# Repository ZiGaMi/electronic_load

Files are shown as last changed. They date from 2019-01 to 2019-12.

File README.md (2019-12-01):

# Electronic Load Rev1.1 
# 
Supports constant current (CC), constant power (CP) and constant resistance modes (CR).

Power rating: 12 W        
Maximum load current: 1 A           
Maximum input voltage: 12 V
 
 Electronic load front:
front

Electronic load backside:
back

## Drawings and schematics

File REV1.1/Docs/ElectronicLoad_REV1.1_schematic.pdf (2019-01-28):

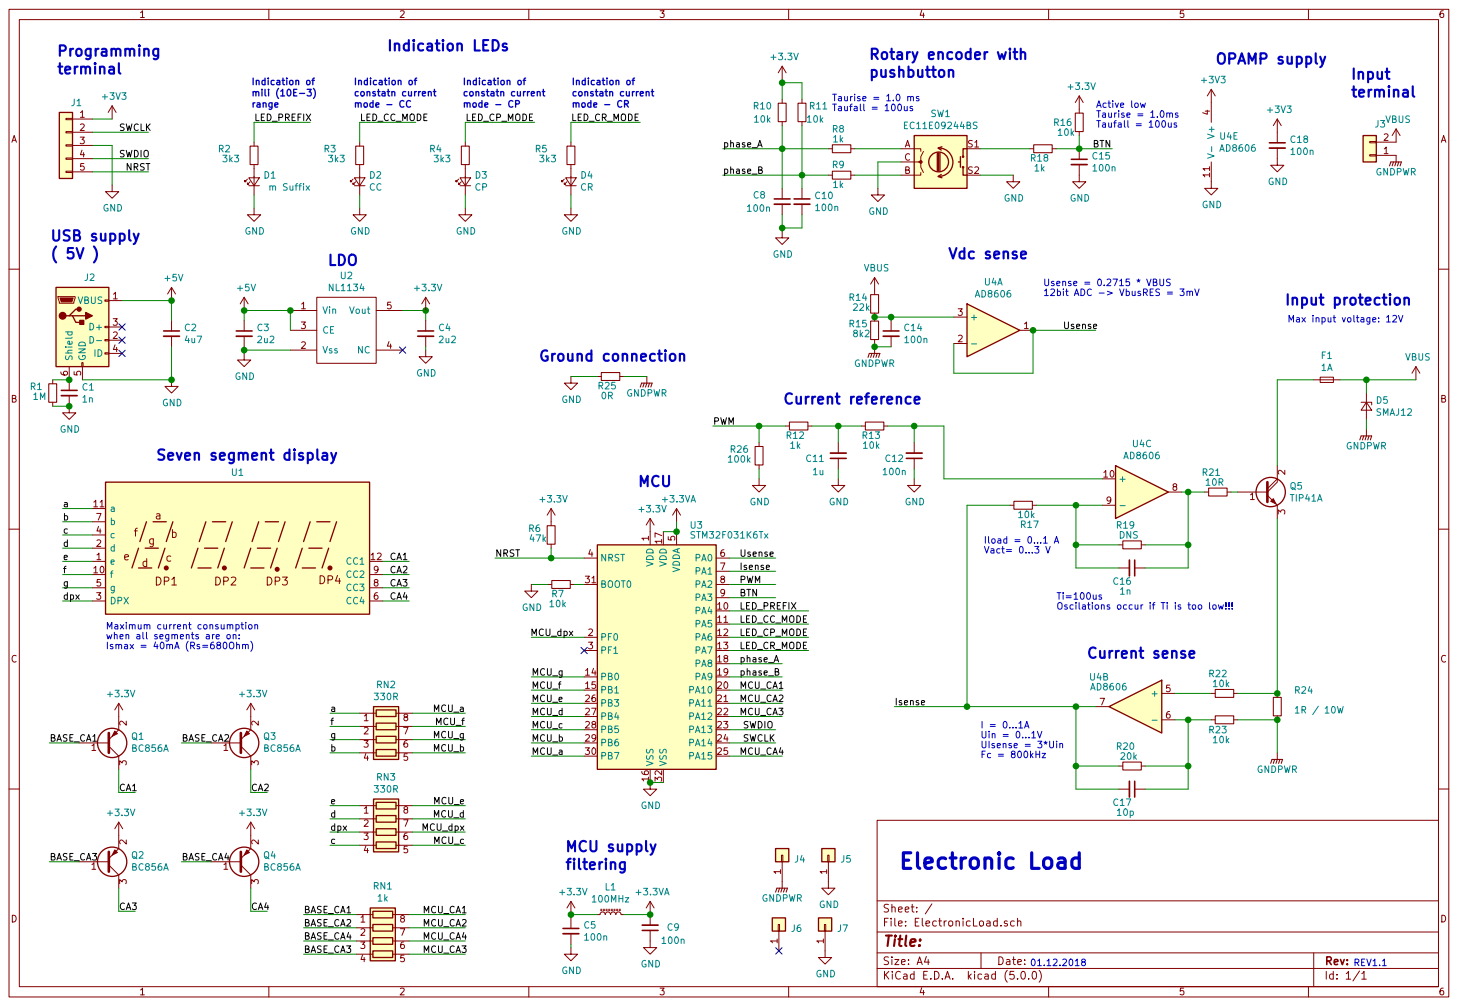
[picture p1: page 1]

Taurise = 1.0ms Taufall = 100us Taurise = 1.0 ms Taufall = 100us Rotary encoder with
pushbutton

Indication of mili (10E-3) range

Indication of constatn current mode - CC

Indication of constatn current mode - CP

Indication of constatn current mode - CR

2 3 Q1BC856A CA1 +3.3V Maximum current consumption
when all segments are on:
Ismax = 40mA (Rs=680Ohm)1

I = 0...1A Uin = 0...1V UIsense = 3*Uin Fc = 800kHz

Id: 1/1 Title: File: ElectronicLoad.sch Sheet: /

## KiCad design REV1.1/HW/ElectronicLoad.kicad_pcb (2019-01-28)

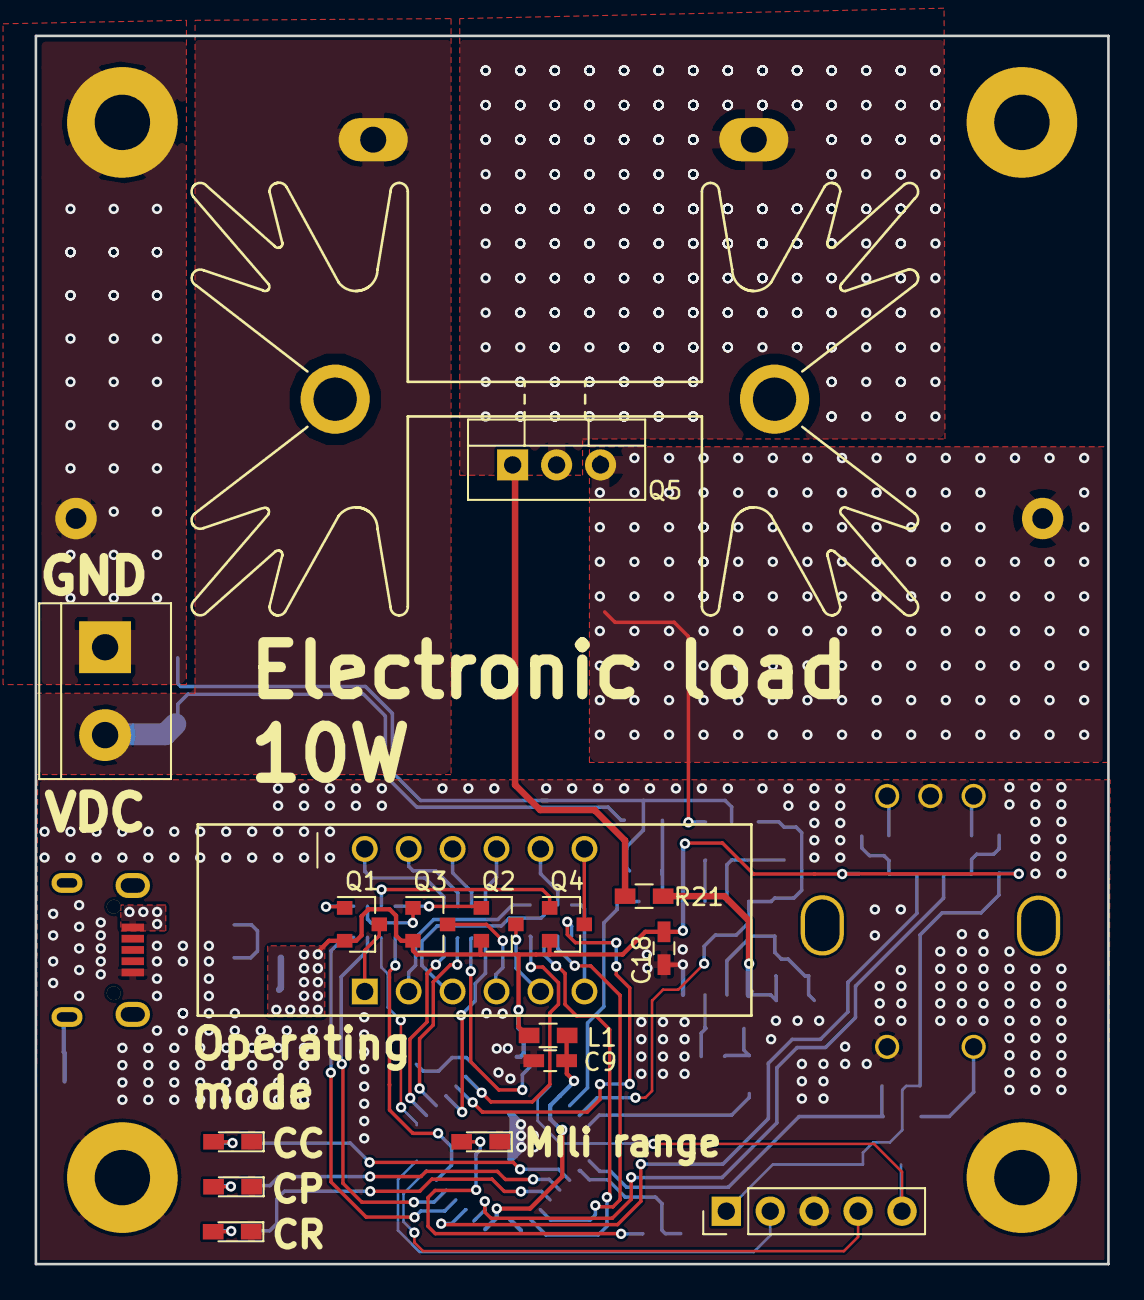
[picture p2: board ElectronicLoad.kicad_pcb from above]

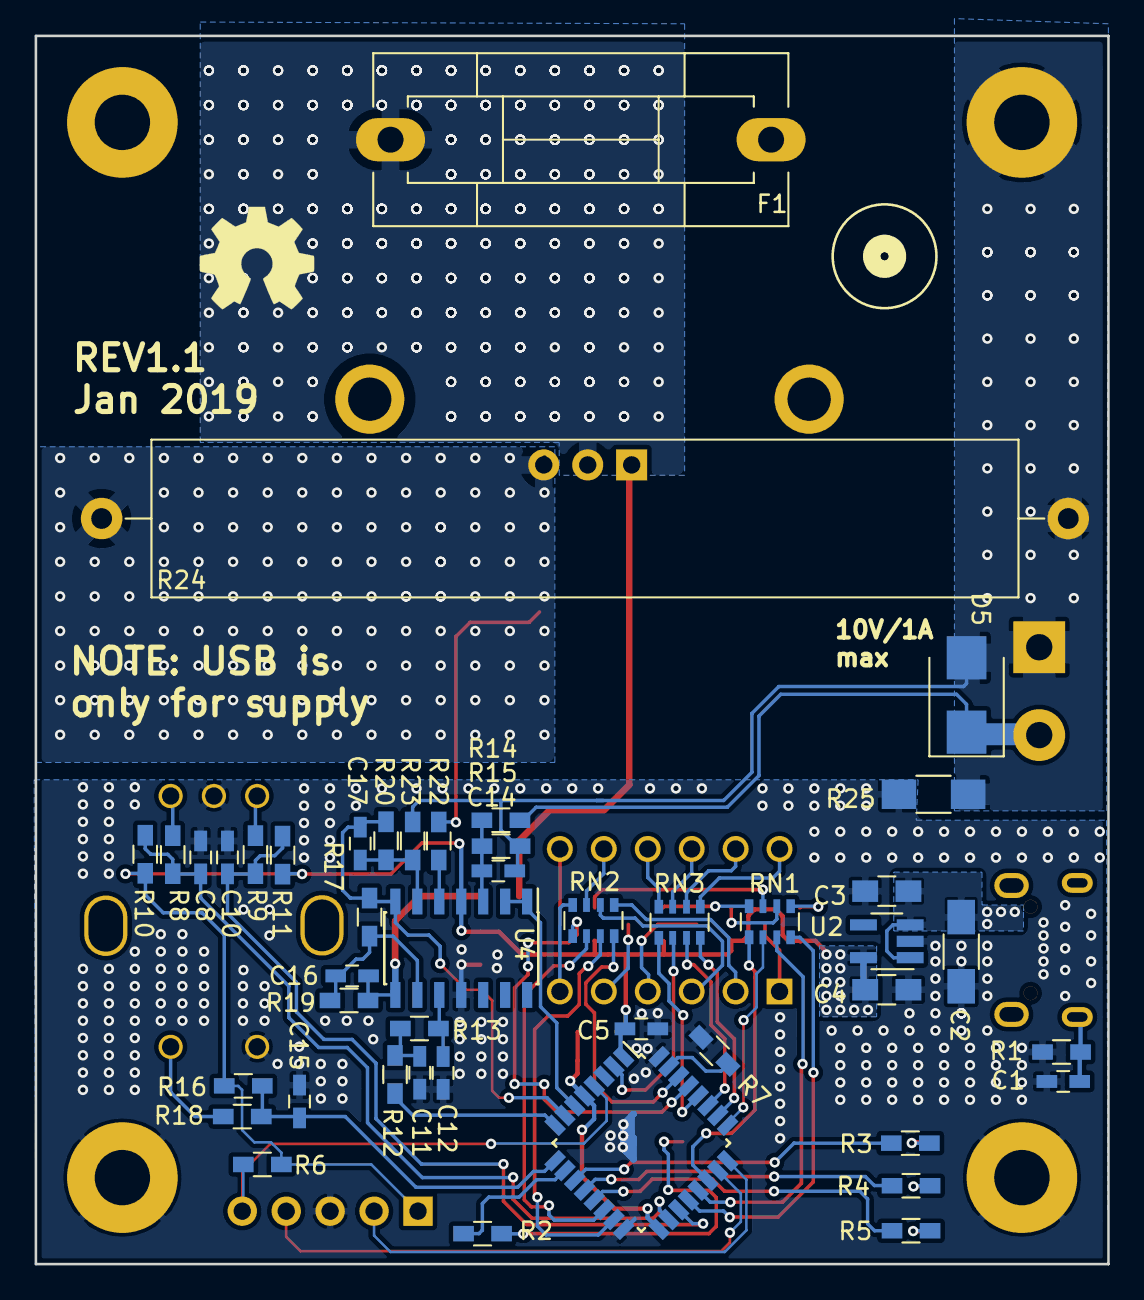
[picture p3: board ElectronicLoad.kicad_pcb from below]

Board: 2 copper layers, 62.0 x 71.0 mm, 67 parts (45 on the bottom side), 66 nets.

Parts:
C1, C16: 1n; C_0603_HandSoldering
C2: 4u7; C_1206_HandSoldering
C3, C4: 2u2; C_0805_HandSoldering
C5, C8, C9, C10, C11, C12, C14, C15, C18: 100n; C_0603_HandSoldering
C17: 10p; C_0603_HandSoldering
D1: m Suffix; LED_0603_HandSoldering
D2: CC; LED_0603_HandSoldering
D3: CP; LED_0603_HandSoldering
D4: CR; LED_0603_HandSoldering
D5: SMAJ12; D_SMB
F1: 1A; Fuseholder5x20_horiz_SemiClosed_Casing10x25mm
J1: Conn_01x05; Pin_Header_Straight_1x05_Pitch2.54mm
J2: USB_B_Micro; USBMicro_629105150521_WE
J3: Conn_01x02; TerminalBlock_bornier-2_P5.08mm
J4, J5, J6, J7: Conn_01x01; MountingHole_3.2mm_M3_Pad
L1: 100MHz; R_0603_HandSoldering
Q1, Q2, Q3, Q4: BC856A; SOT-23
Q5: TIP41A; TO-220-3_Vertical
R1: 1M; R_0603_HandSoldering
R2, R3, R4, R5: 3k3; R_0603_HandSoldering
R6: 47k; R_0603_HandSoldering
R7, R10, R11, R15, R16, R17, R22, R23: 10k; R_0603_HandSoldering
R8, R9, R12, R13, R18: 1k; R_0603_HandSoldering
R14: 27k; R_0603_HandSoldering
R19: DNS; R_0603_HandSoldering
R20: 20k; R_0603_HandSoldering
R21: 10R; R_0603_HandSoldering
R24: 1R / 10W; R_Axial_Power_L50.0mm_W9.0mm_P55.88mm
R25: 0R; R_1206_HandSoldering
RN1: 1k; R_Array_Convex_4x0603
RN2, RN3: 330R; R_Array_Convex_4x0603
SW1: EC11E09244BS
U1: CC56-12SEKWA; 7SegmentLCD_10x32
U2: NL1134; SOT-23-5_HandSoldering
U3: STM32F031K6Tx; LQFP-32_7x7mm_Pitch0.8mm
U4: AD8606; SOIC-14_3.9x8.7mm_Pitch1.27mm

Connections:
+3.3VA: C9.2, L1.2, U3.5, U3.17
+3V3: C4.1, C5.1, C18.1, J1.1, L1.1, Q1.2, Q2.2, Q3.2, Q4.2, R6.1, R10.1, R11.1, R16.1, U2.5, U3.1, U4.4
+5V: C2.1, C3.1, J2.1, U2.1, U2.3
/BASE_CA1: Q1.1, RN1.1
/BASE_CA2: Q3.1, RN1.2
/BASE_CA3: Q2.1, RN1.4
/BASE_CA4: Q4.1, RN1.3
/BTN: C15.1, R16.2, R18.2, U3.9
/CA1: Q1.3, U1.12
/CA2: Q3.3, U1.9
/CA3: Q2.3, U1.8
/CA4: Q4.3, U1.6
/Isense: C17.2, R17.1, R20.2, U3.7, U4.7
/LED_CC_MODE: R3.1, U3.11
/LED_CP_MODE: R4.1, U3.12
/LED_CR_MODE: R5.1, U3.13
/LED_PREFIX: R2.1, U3.10
/MCU_CA1: RN1.8, U3.20
/MCU_CA2: RN1.7, U3.21
/MCU_CA3: RN1.5, U3.22
/MCU_CA4: RN1.6, U3.25
/MCU_a: RN2.8, U3.30
/MCU_b: RN2.5, U3.29
/MCU_c: RN3.5, U3.28
/MCU_d: RN3.7, U3.27
/MCU_dpx: RN3.6, U3.2
/MCU_e: RN3.8, U3.26
/MCU_f: RN2.7, U3.15
/MCU_g: RN2.6, U3.14
/NRST: J1.5, R6.2, U3.4
/PWM: R12.1, U3.8
/SWCLK: J1.2, U3.24
/SWDIO: J1.4, U3.23
/Usense: U3.6, U4.1, U4.2
/a: RN2.1, U1.11
/b: RN2.4, U1.7
/c: RN3.4, U1.4
/d: RN3.2, U1.2
/dpx: RN3.3, U1.3
/e: RN3.1, U1.1
/f: RN2.2, U1.10
/g: RN2.3, U1.5
/phase_A: C8.1, R8.1, R10.2, U3.18
/phase_B: C10.1, R9.1, R11.2, U3.19
GND: C1.2, C2.2, C3.2, C4.2, C5.2, C8.2, C9.1, C10.2, C11.1, C12.1, C15.2, C18.2, D1.1, D2.1, D3.1, D4.1, J1.3, J2.5, J5.1, J7.1, R1.2, R7.1, R25.1, SW1.C, SW1.S2, U2.2, U3.16, U3.32, U4.11
GNDPWR: C14.2, D5.2, J3.1, J4.1, R15.2, R23.1, R24.2, R25.2
unnamed: C1.1, J2.6, R1.1
unnamed: C11.2, R12.2, R13.1
unnamed: C12.2, R13.2, U4.10
unnamed: C14.1, R14.2, R15.1, U4.3
unnamed: C16.1, R19.1, R21.2, U4.8
unnamed: C16.2, R17.2, R19.2, U4.9
unnamed: C17.1, R20.1, R23.2, U4.6
unnamed: D1.2, R2.2
unnamed: D2.2, R3.2
unnamed: D3.2, R4.2
unnamed: D4.2, R5.2
unnamed: F1.1, Q5.2
unnamed: Q5.1, R21.1
unnamed: Q5.3, R22.1, R24.1
unnamed: R7.2, U3.31
unnamed: R8.2, SW1.A
unnamed: R9.2, SW1.B
unnamed: R18.1, SW1.S1
unnamed: R22.2, U4.5
VBUS: D5.1, F1.2, J3.2, R14.1

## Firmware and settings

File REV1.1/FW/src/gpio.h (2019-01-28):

/*
 * gpio.h
 *
 *  Created on: 26.10.2018
 *      Author: ziga.miklosic
 */

#ifndef GPIO_H_
#define GPIO_H_

#include "stm32f031x6.h"


/*
 * 		ADC inputs
 * 	Pins: 	PA0 -> Usense
 * 			PA1 -> Isense
 */
#define SENSE_PORT		( GPIOA )
#define VOL_SENSE_bp	( 0ul )
#define CUR_SENSE_bp	( 1ul )


/*
 * 		TIMER output
 * 	Pin: 	PA2 -> pwm for reference generation
 */
#define CUR_REF_PORT		( GPIOA )
#define CUR_REF_bp		( 2ul )


/*
 * 		PUSH BUTTON ( rotary encoder )
 * 	Pin:	PA3 -> buttons
 *
 * 	NOTE: Active low
 */
#define BUTTON_PORT		( GPIOA )
#define BUTTON_bp		( 3ul )
#define BUTTON_TIMEOUT	( float )	( 1.0f )	// sec


/*
 * 		LEDs INDICATIORS
 *	Pins: 	PA4 -> Range prefix
 *			PA5 -> CC mode
 *			PA6 -> CP mode
 *			PA7 -> CR mode
 */
#define LED_PORT		( GPIOA )
#define LED_RANGE_bp	( 4ul )
#define LED_CC_bp		( 5ul )
#define LED_CP_bp		( 6ul )
#define LED_CR_bp		( 7ul )

/*
 *
 * 		TIMER input ( rotary encoder )
 * 	Pin:	PA8	-> phase A
 * 			PA9 -> phase B
 */
#define ENCODER_PORT	( GPIOA )
#define PHASE_A_bp		( 8ul )
#define PHASE_B_bp		( 9ul )


/*
 * 		SEVEN SEGMENT DISPLAY
 * 	Pin: 	PA10 -> CA1
 * 			PA11 -> CA2
 * 			PA12 -> CA3
 * 			PA13 -> CA4 (SWCLK)
 * 			PB0 -> g
 * 			PB1 -> f
 * 			PB3 -> e
 * 			PB4 -> d
 * 			PB5 -> c
 * 			PB6 -> b
 * 			PB7 -> a
 */
#define CA_PORT		( GPIOA )
#define SEG_PORT	( GPIOB )
#define CA1_bp		( 10ul )
#define CA2_bp		( 11ul )
#define CA3_bp		( 12ul )
#define CA4_bp		( 15ul )
#define SEG_G_bp	( 0ul )
#define SEG_F_bp	( 1ul )
#define SEG_E_bp	( 3ul )
#define SEG_D_bp	( 4ul )
#define SEG_C_bp	( 5ul )
#define SEG_B_bp	( 6ul )
#define SEG_A_bp	( 7ul )

#define DPX_PORT	( GPIOF )
#define DPX_bp		( 0ul )


/*
 * 	GPIO Functions
 */
void GpioInit(void);
void GpioPinOn(GPIO_TypeDef*, uint8_t);
void GpioPinOff(GPIO_TypeDef*, uint8_t);
void GpioPinToggle(GPIO_TypeDef*, uint8_t);

void LedsOff(void);


#endif /* GPIO_H_ */

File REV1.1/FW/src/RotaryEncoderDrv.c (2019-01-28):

/*
 * RotaryEncoder.c
 *
 *  Created on: 29. dec. 2018
 *      Author: ZigaM
 */

#include "RotaryEncoderDrv.h"

// Check rotary encoder
void RotaryEncoderCheck(RotaryEncoderTypedef *RE){

	// Inactive timer
	static float in_active_time = 0.0f;

	// Get ticks - DIVIDE BY TWO (quadrature encoder)
	RE -> cnt = (( TIM1 -> CNT ) >> 1 );

	// Calculate difference
	RE -> cnt_diff = (( RE -> cnt ) - (RE -> cnt_prev ));

	// Check for overflow
	if ( RE -> cnt_diff > 50 )			RE -> cnt_diff = RE -> cnt_diff - ((( ENCODER_MAX_TICKS - 1 ) >> 1 ) + 1 );
	else if ( RE -> cnt_diff < -50 )	RE -> cnt_diff = ((( ENCODER_MAX_TICKS - 1 ) >> 1 ) + 1 ) + RE -> cnt_diff;

	// Store previous counts
	RE -> cnt_prev = ( RE -> cnt );


	// Clear non active time
	if ( RE -> cnt_diff ){
		in_active_time = 0.0f;
	}

	// Increment till inactive
	else if ( RE -> active ){
		in_active_time += ENCODER_TIMER_TIME_s;
	}

	// Check for timer overflow
	if ( in_active_time >= ENCDER_NON_ACTIVE_TIME_s ){
		RE -> active = false;
	}
	else{
		RE -> active = true;
	}
}

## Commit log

2019-01-28 new file: ElectronicLoadDrv.c new file: ElectronicLoadDrv.h new file: RotaryEncoderDrv.c new file: RotaryEncoderDrv.h new file: SevenSegmentDrv.c new file: SevenSegmentDrv.h new file: adc.c new file: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
2019-01-28 new file: ElectronicLoad.kicad_pcb new file: ElectronicLoad.pro new file: ElectronicLoad.sch
    [ElectronicLoad.kicad_pcb, ElectronicLoad.sch]
